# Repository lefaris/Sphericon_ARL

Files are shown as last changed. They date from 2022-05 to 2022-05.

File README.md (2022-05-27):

# Agile Robotics Lab | Sphericon

Sphericon

## Code
### BLE
To run Arduino code using bluetooth low energy connectivity, first install a BLE app such as LightBlue on the app store.  Upload ArdA_Demo.ino to one Arduino Nano 33 BLE, and ArdB_Demo.ino to another Arduino Nano 33 BLE.  Connect a bluetooth device to each Arduino using the LightBlue app.  Once connected, send 0x35 to each Arduino to begin oscillations.

###  No BLE
To run Arduino code without the bluetooth low energy connectivity, upload sphericon_stepper.ino to each Arduino.  As soon as the code is uploaded, the motor assembly will start to swing.  A mechanical switch to enable the start of the code will be added to the PCBs in a future version.

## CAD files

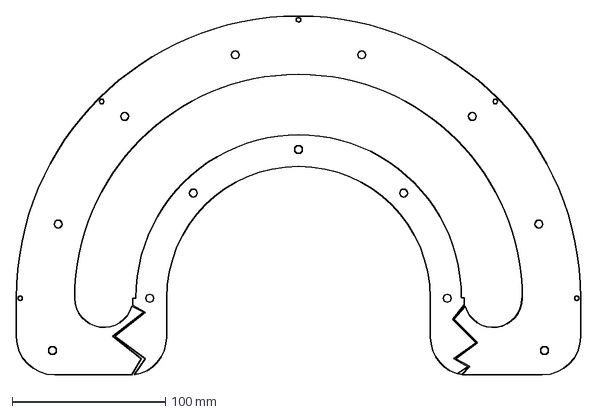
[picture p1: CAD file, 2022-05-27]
CAD/Joshua's New Laser Cut interior.dxf
367.7 x 233.9 mm

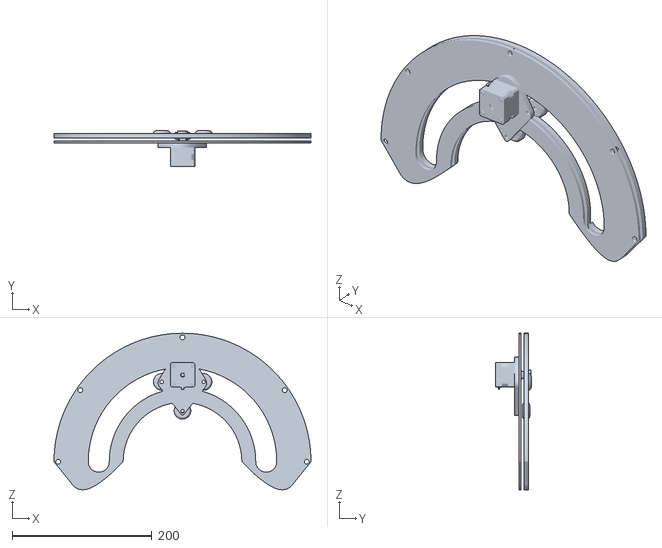
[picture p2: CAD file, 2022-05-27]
CAD/01292021 - ENS - Louis v13.stl
368.3 x 51.4 x 224.3

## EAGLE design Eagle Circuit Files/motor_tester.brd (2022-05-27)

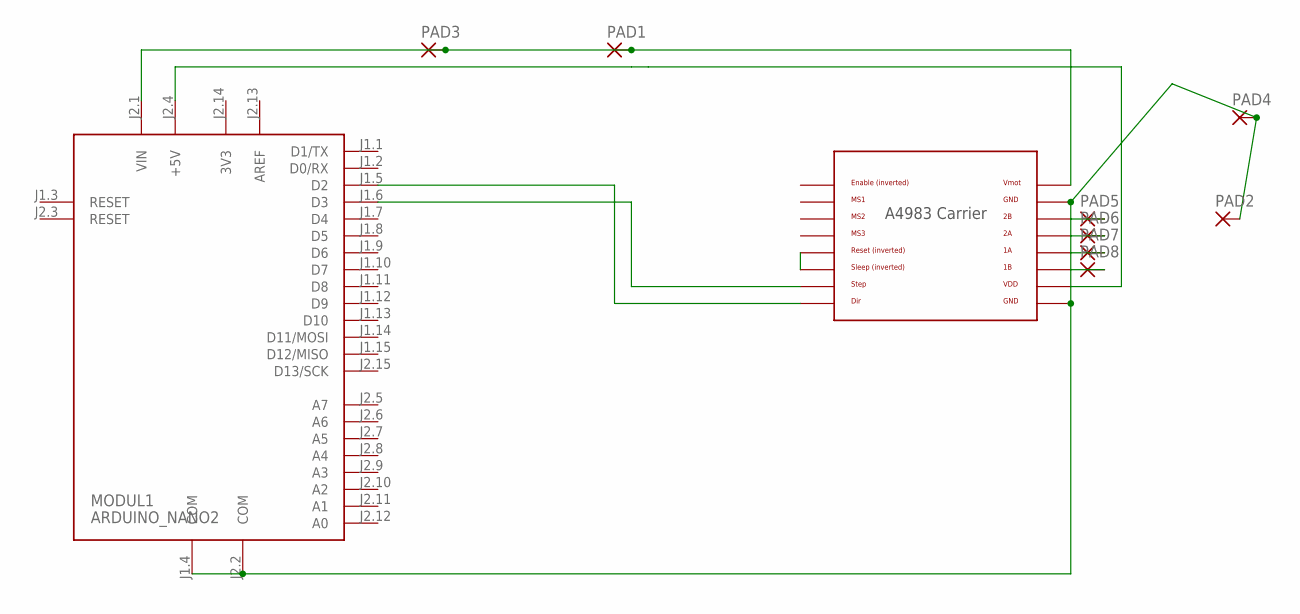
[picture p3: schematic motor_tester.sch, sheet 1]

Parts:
MODUL1: ARDUINO_NANO2
PAD1, PAD2, PAD3, PAD4, PAD5, PAD6, PAD7, PAD8: 1,6/0,8
U$6: POLOLU_A4983CARRIER; A4983CARRIER

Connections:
3V3: MODUL1.J2.14 (3V3)
AREF: MODUL1.J2.13 (AREF)
unnamed: MODUL1.J1.5 (D2), U$6.DIR
unnamed: MODUL1.J1.6 (D3), U$6.STEP
unnamed: MODUL1.J2.1 (VIN), PAD1.1, PAD3.1, U$6.VMOT
unnamed: U$6.RST, U$6.SLP (SLEEP)
unnamed: MODUL1.J1.4 (COM), MODUL1.J2.2 (COM), PAD2.1, PAD4.1, U$6.GND, U$6.GND@0 (GND)
unnamed: PAD5.1, U$6.2B
unnamed: PAD6.1, U$6.2A
unnamed: PAD7.1, U$6.1A
unnamed: PAD8.1, U$6.1B
unnamed: MODUL1.J2.4 (+5V), U$6.VDD

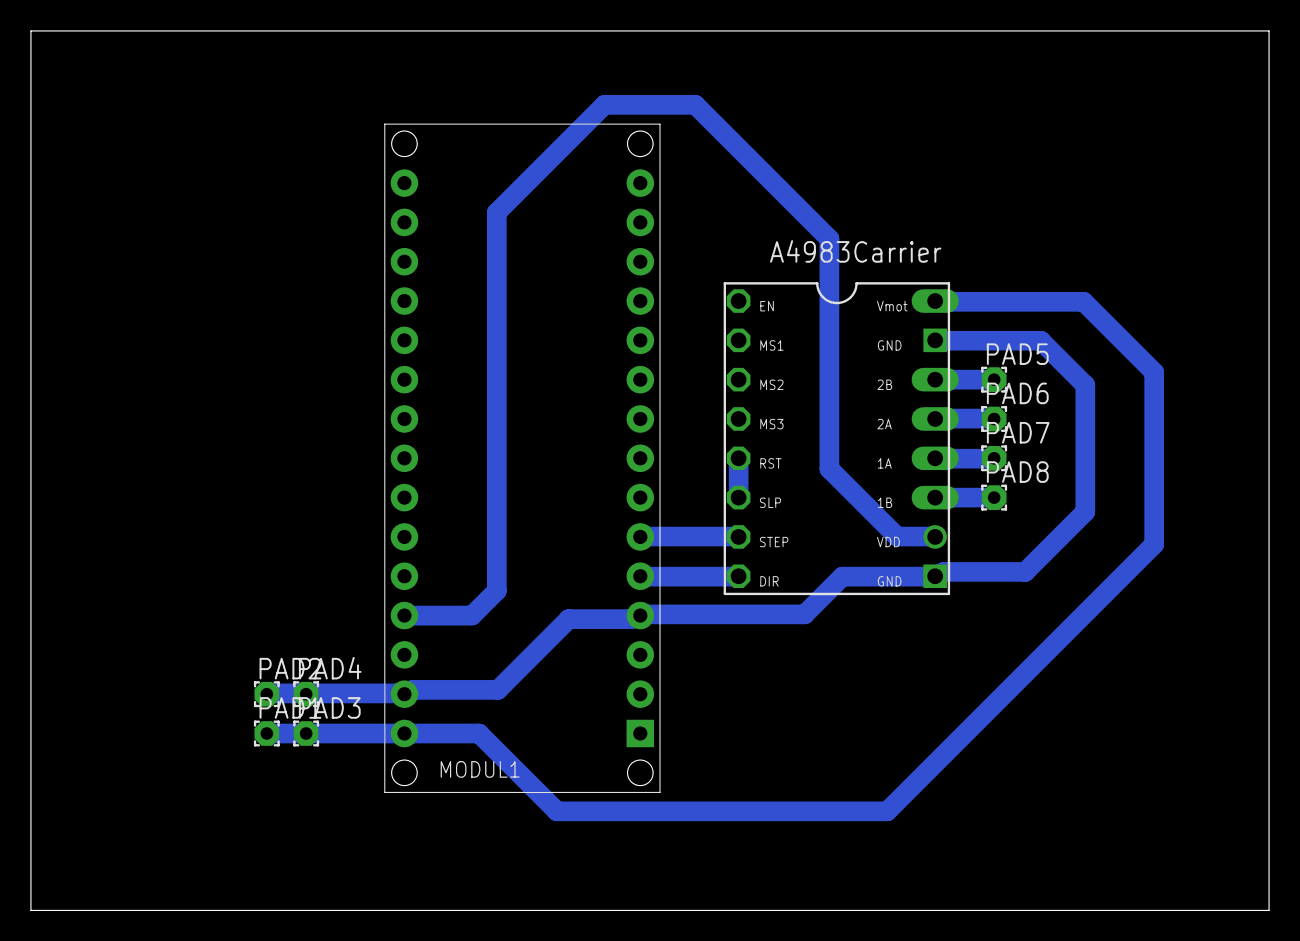
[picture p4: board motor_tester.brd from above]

Board: 2 copper layers, 80.0 x 56.8 mm, 10 parts (0 on the bottom side), 10 nets.

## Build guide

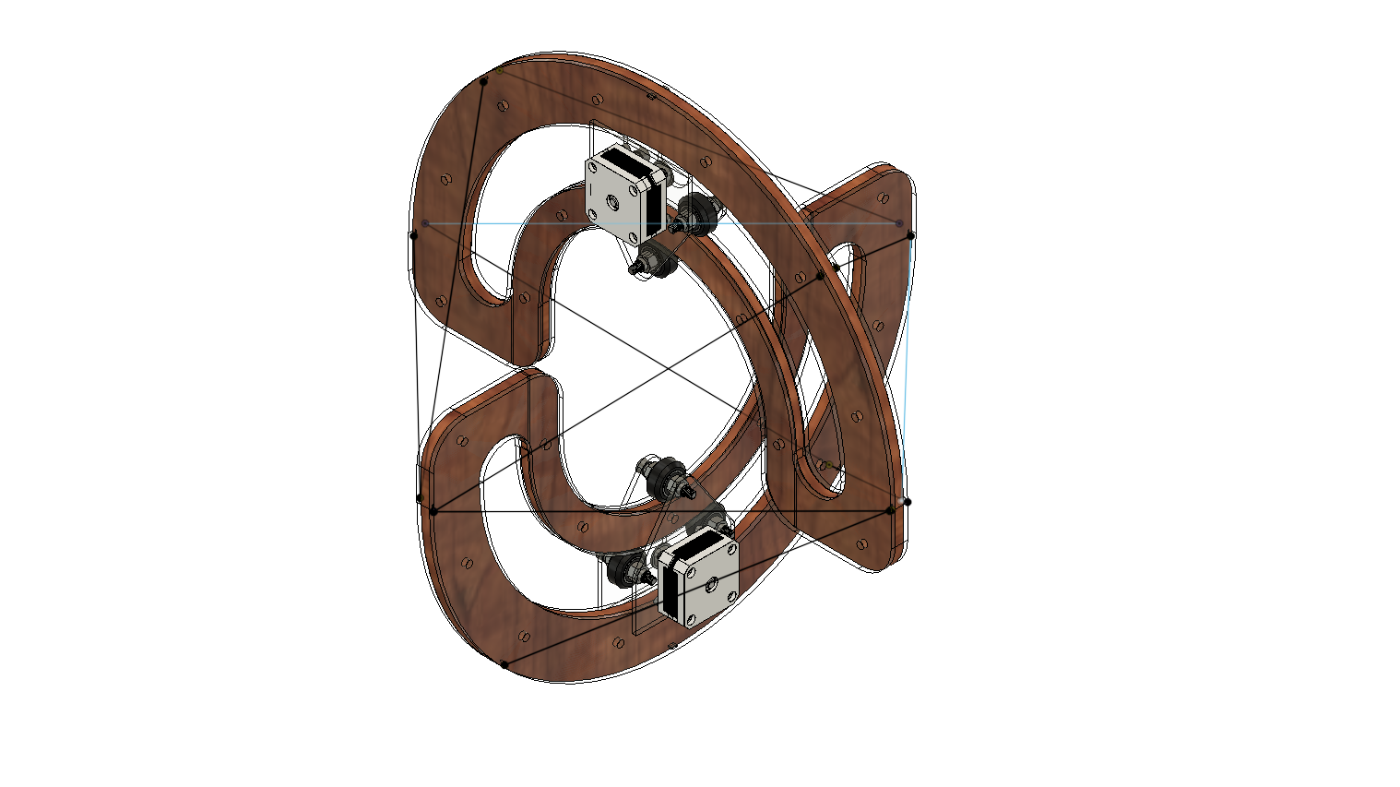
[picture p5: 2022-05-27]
Figures/Assembled Bot Rev 5 v4.png

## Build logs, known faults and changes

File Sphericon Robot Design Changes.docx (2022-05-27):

Sphericon Robot Design Changes

Half Circle Rails:

- Add through slots & holes for strings along the rails
  - Need to be sized according to width of screw
  - Slots will accommodate different material, such as paracord
    - Need to experiment with washers
- Extend the ends beyond just the half circle.
  - Allows the motor assembly to oscillate the full half circle.
  - Need to make sure that the size of of the assembly still fits inside the laser cutter
- Extend the diameter of the sphereicon
  - This should solve the issue of the strings hitting the motor assembly
  - Keep inner diameter the same
- Use one piece acrylic construction
  - Will prevent the motor from sticking to the ledge caused by the break
- Look into ways to increase traction
  - One group used a rubber paint/coating

Motor Assembly

- Add end stops that detect the maximum and minimum
  - Will help drastically with startup and oscillations
  - Need to change code
- Look into alternate gears to prevent motor slipping / change torque
  - This isn’t a high priority
- Fabricate dust cover for circuit

Control Circuit

- Finish Othermill board design phase
  - Testing is required for these boards
    - Probably lots of potential improvements, like adding through holes for mounting
- Make other borads for different controllers?
  - Do we want to stick with Nano 33 BLE if we aren’t using BLE

Code

- Finish BLE investigation
  - Is it really not possible?
- Find alternatives to sync motors together
  - Avoid wired interface, maybe external chip is needed
- Once end stops are implemented, change code
- Add more in depth control variables
  - RPM/Oscillations per Minute
  - Oscillation offset

System Changes

- Flat Packing system
  - Motor + Controller that change the tension elements
  - Sense tension and adjust correspondingly
    - Use this to control pathing?
- Adding other sensors
  - Used to verify simulations and makes the robot “useful”
  - Gyroscope
  - Accelerometer
  - Camera
  - Scientific measurement tools
- Material changes
  - We are already planning to swap to thicker acrylic
  - Maybe use a metal inner section?
  - Use paracord for tension elements
    - Do we want to try elastic?

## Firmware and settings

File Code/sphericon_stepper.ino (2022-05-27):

//Lower bound is: 00 in hex or 0 in decimal
//Upper bound is: 1E in hex or 30 in decimal
//Total length is: 1E

#define stepPinA 3
#define dirPinA 2
#define stepDelay 500 // Delay (microseconds) of the motor between steps.
#define stepCounter 50 // # of time the move commands loop 
int stopValueA = 30; // sets max value of stepper motor, min is set to 0.
int oscilationCounter;
int motorAControl;
int counterA; // global variables

int stepCount = 0;         // number of steps the motor has taken

void setup() {
  oscilationCounter = 0;

  pinMode(stepPinA, OUTPUT);
  pinMode(dirPinA, OUTPUT);
  counterA = (stopValueA / 2); //initilizes counter variable: sets to 500 becuase that is the middle of the spectrum
  motorAControl = 53; //Sets initial value (0 = off)
}

void loop() {
  digitalWrite(LED_BUILTIN, HIGH); // turns built in LED on

  if (motorAControl == 0) {
    int oscilationCounter = 0; //resets counter
  }

  if (motorAControl != 0) {
        //Oscilate motor A once
        if (motorAControl == 53 ) { //Hex Value 35
          if (counterA == stopValueA) {
            oscilationCounter = 1;
          }
          else if (counterA == 0){
           oscilationCounter = 0;
          }
          
          if ((counterA < stopValueA) && (oscilationCounter == 0)) {
            while ( counterA < stopValueA ) {
              moveAUpOne(); 
            }
            delay(3000);
            while (counterA > 0){
              moveADownOne();
            }
            delay(3000);
          }
          else if ((counterA > 0)&&(oscilationCounter == 1)) {
            while(counterA > 0){
              moveADownOne();
            }
            delay(3000);
            while (counterA < stopValueA) {
              moveAUpOne(); 
            }
            delay(3000);
          }
        }

        //oscilate motor A until another command is input. 
        else {
          motorAControl = 0;
        }
       }//End of motor A's Loop
}


void moveAUpOne() { //moves the stepper motor up one counter
   digitalWrite(dirPinA, HIGH);
   digitalWrite(LED_BUILTIN, HIGH);
   for(int x = 0; x < stepCounter; x++){
    digitalWrite(stepPinA, HIGH);
    delayMicroseconds(stepDelay);
    digitalWrite(stepPinA, LOW);
    delayMicroseconds(stepDelay);
  }
  digitalWrite(LED_BUILTIN, LOW);
  counterA++;
}

void moveADownOne() { //moves the stepper motor up one counter
   digitalWrite(dirPinA, LOW);
   digitalWrite(LED_BUILTIN, HIGH);
   for(int x = 0; x < stepCounter; x++){
    digitalWrite(stepPinA, HIGH);
    delayMicroseconds(stepDelay);
    digitalWrite(stepPinA, LOW);
    delayMicroseconds(stepDelay);
  }
  digitalWrite(LED_BUILTIN, LOW);
  counterA--;
}

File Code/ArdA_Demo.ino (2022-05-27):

//Global Constants
//const int ledPin = 2;
const int StepPin = 3;
const int DirPin = 2;
const int stepDelay = 300; // Delay (microseconds) of the motor between steps.
const int stepCounter = 50; // # of time the move commands loop 
int stopValueA = 30; // sets max value of stepper motor, min is set to 0.
int oscilationCounter;
bool setUp;

int Counter; // global variables


#include <ArduinoBLE.h> 
#include <Arduino_LSM6DS3.h> 
#include <Arduino.h>

BLEService TenseRoboA("0fcf5793-df75-475c-be63-62affc3fbbf9"); //UUID for turning a LED on
BLEByteCharacteristic MotorPosition("bbf8", BLERead | BLENotify); //UUID for monitering
BLEByteCharacteristic MotorControl("bbf7", BLERead | BLENotify | BLEWrite); //UUID for Writing to A
BLEBoolCharacteristic OscStatus("bbf9", BLERead | BLENotify | BLEWrite); //UUID for Writing to A


 
void setup() {
  setUp = true;
  oscilationCounter = 0;
  pinMode(StepPin, OUTPUT);
  pinMode(DirPin, OUTPUT);
  Counter = (stopValueA / 2); //initilizes counter variable:
  if (!BLE.begin()) {
    while (1); //stop program becuase it won't work
  } //notifies via //Serial if BLE is not working
  
  BLE.setLocalName("TensegrityRobotA"); //sets name for device
  BLE.setAdvertisedService(TenseRoboA);
  TenseRoboA.addCharacteristic(MotorPosition); //adds  to controlLed
  TenseRoboA.addCharacteristic(MotorControl); //adds  to controlLed
  TenseRoboA.addCharacteristic(OscStatus); //adds  to controlLed

  BLE.addService(TenseRoboA); //adds  to TensegrityRobot
  MotorPosition.writeValue(Counter); //Sets initial value to counter
  MotorControl.writeValue(0); //Sets initial value (0 = off)
  OscStatus.writeValue(0); //Sets initial value to false
  BLE.advertise(); //advertises TenseRoboA 

}

void loop() {
BLEDevice central = BLE.central(); //Sets a boolean "central" to notify if connection has occured
//setup loop, set bounds with BLE main
  if (central) { // central = device connected
    digitalWrite(LED_BUILTIN, HIGH); // turns built in LED on    
    while(central.connected()) {
      //This if tree tells the motor what to do
      if (MotorControl.value() == 0) {
        int oscilationCounter = 0;//resets the counter after a different command is executed
      }
      if (MotorControl.value() != 0) {
        //default and debug statuses
        if(MotorControl.value() == 1) { //default response
          MotorPosition.writeValue(Counter);
          MotorControl.writeValue(0);
        }else if (MotorControl.value() == 2) { //counter has reached stopValue
          MotorControl.writeValue(0);
        }else if (MotorControl.value() == 3) { //counter has reached 0
          MotorControl.writeValue(0);
        }
        
        //these cases move counter up
        else if (MotorControl.value() == 16 ) { //Hex Value 10
          if (Counter < stopValueA) {
            moveAUpOne();
          } else {
            MotorControl.writeValue(2);
          }
        }else if (MotorControl.value() == 17 ) { //Hex Value 11
          if (Counter < stopValueA) {
            moveAUpOne();
            MotorControl.writeValue(1);
          } else {
            MotorControl.writeValue(2);
          }
        }else if (MotorControl.value() == 21 ) { //Hex Value 15
          if (Counter < stopValueA) {
            for (int i = 0; i<5; i++) { 
              moveAUpOne();
            }
            MotorControl.writeValue(1);
          } else {
            MotorControl.writeValue(2);
          }
        }
        
        //these cases move counter down
        else if (MotorControl.value() == 32 ) { //Hex Value 20
          if (Counter > 0) {
            moveADownOne();
          } else {
            MotorControl.writeValue(3);
          }
        }else if (MotorControl.value() == 33 ) { //Hex Value 21
          if (Counter > 0) {
            moveADownOne();
            MotorControl.writeValue(1);
          } else {
            MotorControl.writeValue(3);
          }
        }else if (MotorControl.value() == 37 ) { //Hex Value 25
          if (Counter > 0) {
            for (int i = 0; i<5; i++) { 
              moveADownOne();
            }
            MotorControl.writeValue(1);
          } else {
            MotorControl.writeValue(3);
          }
        }
        //
        else if(MotorControl.value() == 49 ){ //Hex Value 31
          Counter = 0; 
        }
        //This case sets the maximum value of counter to be what the counter currently is. This is the other endpoint
        else if(MotorControl.value() == 50 ){ //Hex Value 32
          stopValueA = Counter;
        }
        //Resets the counter to the middle value if messed up
        else if(MotorControl.value() == 51 ){ //Hex Value 33
          Counter = (stopValueA /2); 
        }
        //This case sets the maximum value of counter to 1000, serves as reset of Hex value 32.
        else if(MotorControl.value() == 52 ){ //Hex Value 34
          stopValueA = 1000;
        }

        else if(MotorControl.value() == 53 ){ //Hex Value 35
          if (Counter == stopValueA) {
          oscilationCounter = 1;
          }
          else if (Counter == 0){
           oscilationCounter = 0;
          }
          if ((Counter < stopValueA) && (oscilationCounter == 0)) {
            while ( Counter < stopValueA ) {
              moveAUpOne(); 
            }
            delay(3000);
            while (Counter > 0){
              moveADownOne();
            }
            delay(3000);
          }
          else if ((Counter > 0)&&(oscilationCounter == 1)) {
            while(Counter > 0){
              moveADownOne();
            }
            delay(3000);
            while (Counter < stopValueA) {
              moveAUpOne(); 
            }
            delay(3000);
          }
        }
        else {
          //Serial.print("Written Value of ");
          //Serial.print(MotorControl.value());
          //Serial.println(" does not match any commands, try another value."); 
          MotorControl.writeValue(0);
        }
      }
    }
  }

}

void moveAUpOne() { //moves the stepper motor up one counter
   digitalWrite(DirPin, HIGH);
   digitalWrite(LED_BUILTIN, HIGH);
   for(int x = 0; x < stepCounter; x++){
    digitalWrite(StepPin, HIGH);
    delayMicroseconds(stepDelay);
    digitalWrite(StepPin, LOW);
    delayMicroseconds(stepDelay);
  }
  digitalWrite(LED_BUILTIN, LOW);
  Counter++;
}

void moveADownOne() { //moves the stepper motor up one counter
   digitalWrite(DirPin, LOW);
   digitalWrite(LED_BUILTIN, HIGH);
   for(int x = 0; x < stepCounter; x++){
    digitalWrite(StepPin, HIGH);
    delayMicroseconds(stepDelay);
    digitalWrite(StepPin, LOW);
    delayMicroseconds(stepDelay);
  }
  digitalWrite(LED_BUILTIN, LOW);
  Counter--;
}
